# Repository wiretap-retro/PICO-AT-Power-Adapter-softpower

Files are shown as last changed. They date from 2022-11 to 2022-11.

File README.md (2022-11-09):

# PICO-AT Power Adapter - softpower version
A version of the regular PICO-AT adapter, but with momentary power switch support.

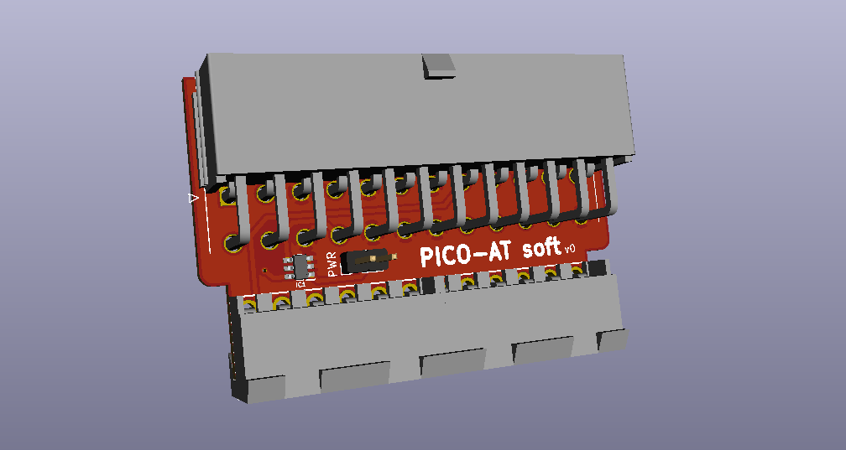
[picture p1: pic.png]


## Intro
I designed this board for a small SBC that I could not fit a large power supply in the enclosure. This design is recommended for PICO-PSU units, and can be used with various retro motherboards that have the AT-style power connector. It is not recommended to pass sustained high current over 8-amps on any single power rail through this PCB. This version utilizes a power switch with momentary actuation. 

## Building
* Detailed BOM for Mouser parts is included. Subsitutions may be necessary depending on the chip/component shortages.
* Solder the SMD components first, then solder the through-hole components. The 7905 component will need to be flush clipped with the board before soldering, to ensure the ATX connector sits flat.
* Depending on your motherboard, this may not fit without modification to the motherboard's power connector. You will need to have the square pins on the power connector, not the larger round pins or flat pins. Most AT boards have the flat pins. See notes section below.

## Notes
* Molex only produced the flat style AT pin header (8619) for use with the 90331 power supply connectors. The flat pin 8619 style motherboard side connectors were only used on AT motherboards to a certain time period, then Molex discontinued the 8619 and replaced it with the KK 396 square pin connector, which is compatible with the 90331 connector as well as KK 396 female connectors, obviously. I only have one motherboard in my collection that came standard with the KK 396 connector. If the motherboard uses the old 8619 connector, it would need to be replaced with the KK 396 type. So, with the KK 396 compatible with both the 90331 and KK 396 itself, you lose no functionality with an original AT power supply connector. I have validated this with motherboards I have converted. The part number for the motherboard side is Molex 41791-0836. (2 required)
* The power switch pin header is for connecting a standard momentary switch to control the ATX power supply's on/off state. You can wire it to your ATX case's power switch. The Maxim MAX16054 chip controls the power on/off state. One press for on, one press for off, with debounce integrated.

## Community Works
Check out Vogons.org for the thread where people are building these and also modifying the design to have fan headers and other cool stuff: https://www.vogons.org/viewtopic.php?f=46&t=86465

## Other
This is an open source design. Feel free to do what you want with it.

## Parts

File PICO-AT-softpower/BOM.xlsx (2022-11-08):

Reference | Value | Footprint | Description | Manufacturer Name | Manufacturer Part Number
J1 | 09-48-1064 | 9481064 | Headers & Wire Housings 6 POS RECEPT .156 R/A PCB TIN | Molex | 09-48-1064
J2 | 09-48-1064 | 9481064 | Headers & Wire Housings 6 POS RECEPT .156 R/A PCB TIN | Molex | 09-48-1064
J3 | 87427-2402 | 87427-2402 | Mini-Fit Jr. Header, 4.20mm Pitch, Right-Angle, without Flange, 24 Circuits, Tin (Sn) over Nickel (Ni) Plating Series: 87427 | Molex | 87427-2402
U1 | L7905 | Package_TO_SOT_THT:TO-220-3_Horizontal_TabDown | L7905, TO-220-3
C2 | 1uF | Capacitor_Tantalum_SMD:CP_EIA-6032-28_Kemet-C_Pad2.25x2.35mm_HandSolder | 1uF EIA-6032-28 Tantalum Capacitor
C1 | 2.2uF | Capacitor_Tantalum_SMD:CP_EIA-6032-28_Kemet-C_Pad2.25x2.35mm_HandSolder | 2.2uF EIA-6032-28 Tantalum Capacitor
D1 | LED | LED_SMD:LED_0805_2012Metric_Pad1.15x1.40mm_HandSolder | 0805 LED
D2 | LED | LED_SMD:LED_0805_2012Metric_Pad1.15x1.40mm_HandSolder | 0805 LED
D3 | LED | LED_SMD:LED_0805_2012Metric_Pad1.15x1.40mm_HandSolder | 0805 LED
R1 | 330 | Resistor_SMD:R_0805_2012Metric_Pad1.15x1.40mm_HandSolder | 0805 330-ohm Capacitor
R2 | 330 | Resistor_SMD:R_0805_2012Metric_Pad1.15x1.40mm_HandSolder | 0805 330-ohm Capacitor
R3 | 1k | Resistor_SMD:R_0805_2012Metric_Pad1.15x1.40mm_HandSolder | 0805 1k-ohm Capacitor
D4 | LED | LED_SMD:LED_0805_2012Metric_Pad1.15x1.40mm_HandSolder | 0805 LED
R4 | 330 | Resistor_SMD:R_0805_2012Metric_Pad1.15x1.40mm_HandSolder | 0805 330-ohm Capacitor
J4 | PWR_SW | Connector_PinHeader_2.54mm:PinHeader_1x02_P2.54mm_Vertical | 1x02 2.54mm Pitch Pin Header
IC1 | MAX16054AZT+T | SOT95P275X110-6N | On Off Controller, Debounce, 15kV ESD MAX16054AZT+T, Voltage Supervisor No Push Button Controller 6-Pin SOT-23 | Maxim Integrated | MAX16054AZT+T

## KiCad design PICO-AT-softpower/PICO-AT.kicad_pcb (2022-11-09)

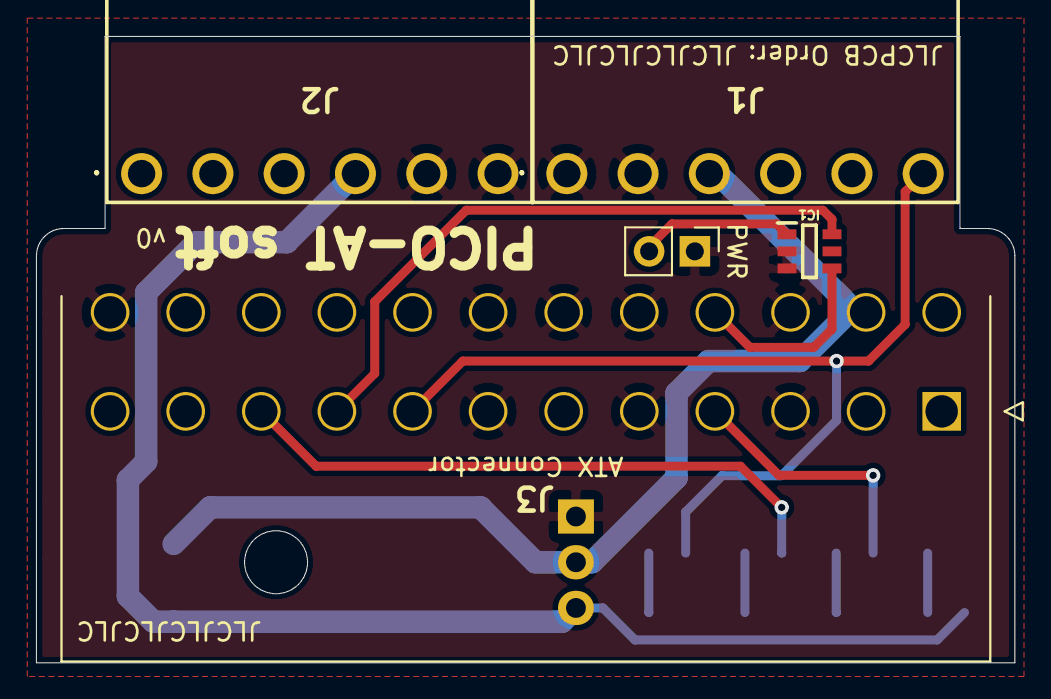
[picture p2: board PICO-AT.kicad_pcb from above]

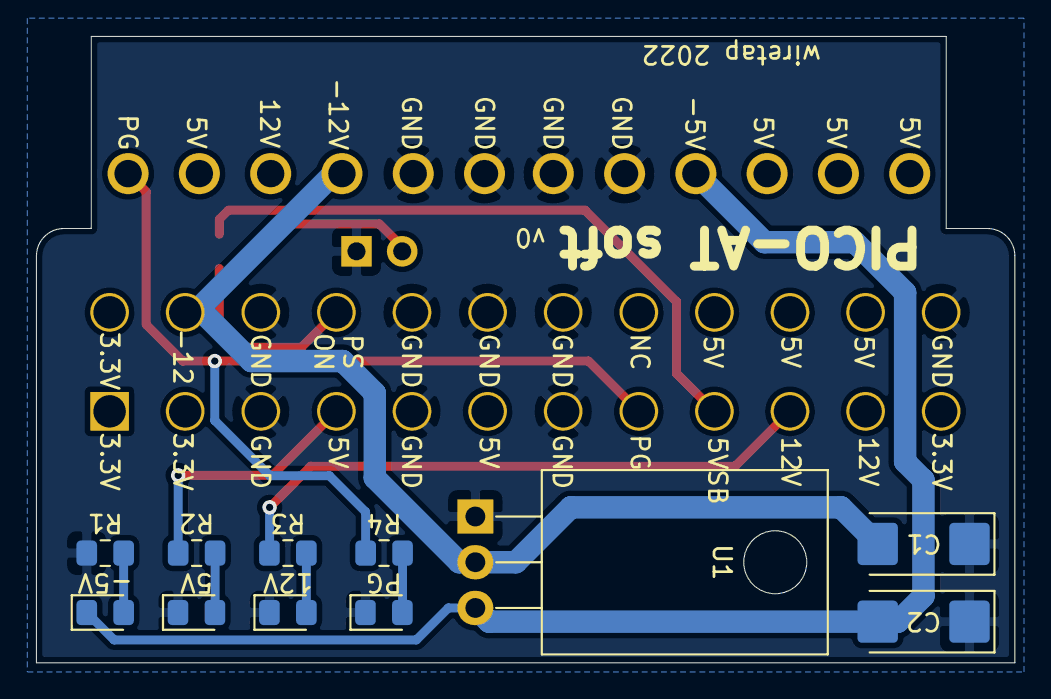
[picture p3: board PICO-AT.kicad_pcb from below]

Board: 4 copper layers, 54.4 x 34.8 mm, 16 parts (11 on the bottom side), 14 nets.

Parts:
5V, 12V: LED; LED_0805_2012Metric_Pad1.15x1.40mm_HandSolder
-5V: LED; LED_0805_2012Metric_Pad1.15x1.40mm_HandSolder
C1: 2.2uF; CP_EIA-6032-28_Kemet-C_Pad2.25x2.35mm_HandSolder
C2: 1uF; CP_EIA-6032-28_Kemet-C_Pad2.25x2.35mm_HandSolder
IC1: MAX16054AZT+T; SOT95P275X110-6N
J1, J2: 09-48-1064; 09481064
J3: 87427-2402
PG: LED; LED_0805_2012Metric_Pad1.15x1.40mm_HandSolder
PWR: PWR_SW; PinHeader_1x02_P2.54mm_Vertical
R1, R2, R4: 330; R_0805_2012Metric_Pad1.15x1.40mm_HandSolder
R3: 1k; R_0805_2012Metric_Pad1.15x1.40mm_HandSolder
U1: L7905; TO-220-3_Horizontal_TabDown

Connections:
/3.3V: J3.1, J3.2, J3.12, J3.13
/5V: J1.5, J2.1, J2.2, J2.3, J3.4, J3.6, J3.21, J3.22, J3.23, R2.1
/5VSB: IC1.6, J3.9
/12V: J1.4, J3.10, J3.11, R3.1
/-5V: -5V.1, C2.2, J2.4, U1.3
/-12V: C1.2, J1.3, J3.14, U1.2
/GND: 5V.1, 12V.1, C1.1, C2.1, IC1.2, IC1.3, J1.1, J1.2, J2.5, J2.6, J3.3, J3.5, J3.7, J3.15, J3.17, J3.18, J3.19, J3.24, PG.1, PWR.1, R1.1, U1.1
/PG: J1.6, J3.8, R4.1
/PS-ON: IC1.4, J3.16
unnamed: -5V.2, R1.2
unnamed: 5V.2, R2.2
unnamed: 12V.2, R3.2
unnamed: PG.2, R4.2
unnamed: IC1.1, PWR.2
